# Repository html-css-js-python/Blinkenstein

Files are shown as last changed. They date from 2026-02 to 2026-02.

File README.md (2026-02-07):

# Blinkenstein

Blinkenstein is a simple KiCad PCB design intended as a functional test board.
It is designed to verify PCB manufacturing quality, assembly correctness, and basic
circuit functionality using classic CMOS logic.

## 1. Overview

Blinkenstein is an LED sequencing circuit built primarily from through-hole components,
with one SMD component included to verify mixed-technology assembly.
The design emphasizes simplicity, low power consumption, and ease of visual inspection.

## 2. Functional Description

The circuit sequentially activates LED pairs in the following order:

`RED → GREEN → BLUE → YELLOW`

Although eight LEDs are present on the PCB, only two LEDs are active at any given time.
The circuit serves as a functional indicator rather than a lighting device.

The core of the design is a CD4017 decade counter.
Clock pulses are generated by a discrete oscillator based on the tunneling effect.
These pulses are inverted and conditioned by a NOT gate with a Schmitt trigger input,
providing a clean and stable clock signal for the counter.

## 3. Schematic Diagram

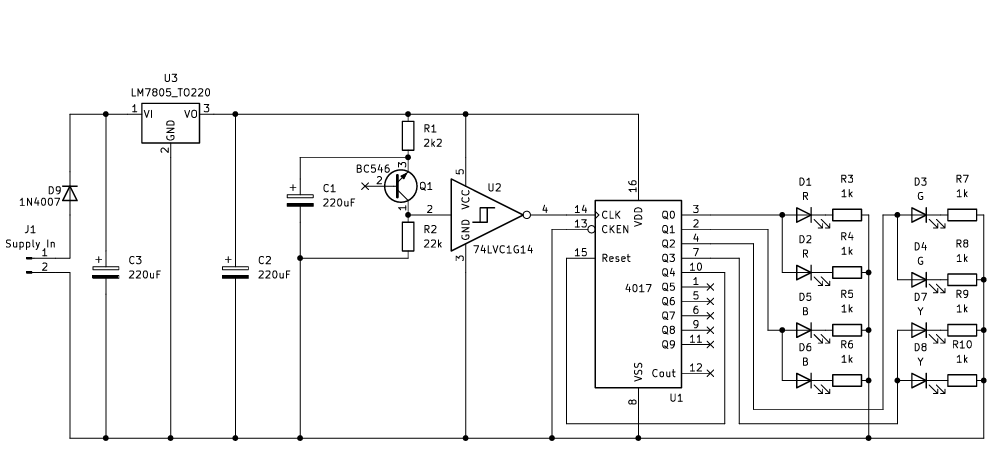
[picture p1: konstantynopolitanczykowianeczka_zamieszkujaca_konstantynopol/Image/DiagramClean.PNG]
Circuit Diagram

Figure 1. Blinkenstein schematic diagram

## 4. Electrical Characteristics

### 4.1 Recommended Operating Conditions

| Parameter | Symbol | Min | Typ | Max | Unit |
|---|---|-----|-----|-----|---|
| Supply Voltage | VCC | 7 | 9 | 12  | V |
| Supply Current | ICC | - | 100 | TBD | mA |
| Ambient Temperature  | TA | -20 | 25  | 60  | °C |

### 4.2 Power Consumption

| Operating Mode | Supply Voltage | Current | Notes |
|---|---|---|---|
| Normal operation | 9 V | ~100 mA | Two LEDs active  |

## 5. Power Supply Requirements

- DC input voltage range: 7–12 V
- Recommended supply voltage: 9 V
- Typical current consumption: ~100 mA
- External regulation not required

## 6. PCB and Assembly Notes

- Majority of components: through-hole
- One component: SMD (for mixed-technology assembly testing)
- Suitable for hand soldering and reflow (SMD component)

## 7. Intended Applications

- PCB manufacturing test board
- Assembly verification (THT + SMD)
- Educational demonstrations (CMOS counters and oscillators)
- Visual functional indicator

## 8. Project Files

All project files (schematic, PCB layout, Gerber)
are located in the following directory:

**[Project Files](/konstantynopolitanczykowianeczka_zamieszkujaca_konstantynopol)**

## 9. Notes

This project is not intended for high-power or precision timing applications.
Component values may be adjusted without affecting core functionality.
Original project name (may appear on schematics and PCB): `Migacz`

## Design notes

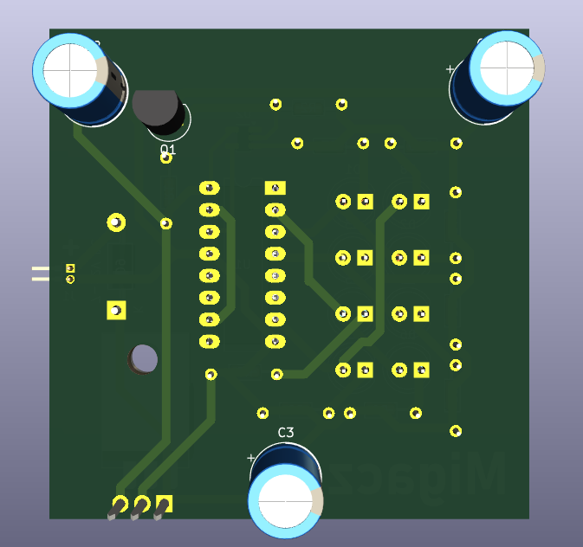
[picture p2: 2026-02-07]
konstantynopolitanczykowianeczka_zamieszkujaca_konstantynopol/Image/Model/BottomM.PNG

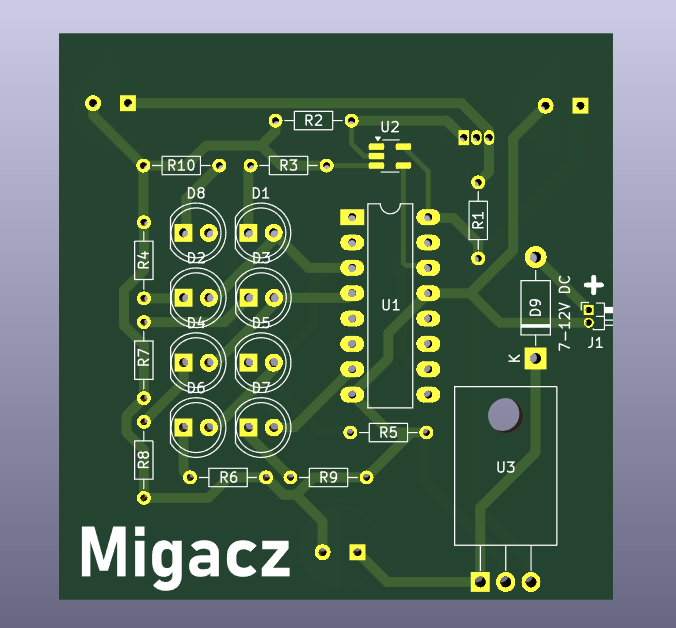
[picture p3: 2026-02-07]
konstantynopolitanczykowianeczka_zamieszkujaca_konstantynopol/Image/PCB/PCBTop.PNG

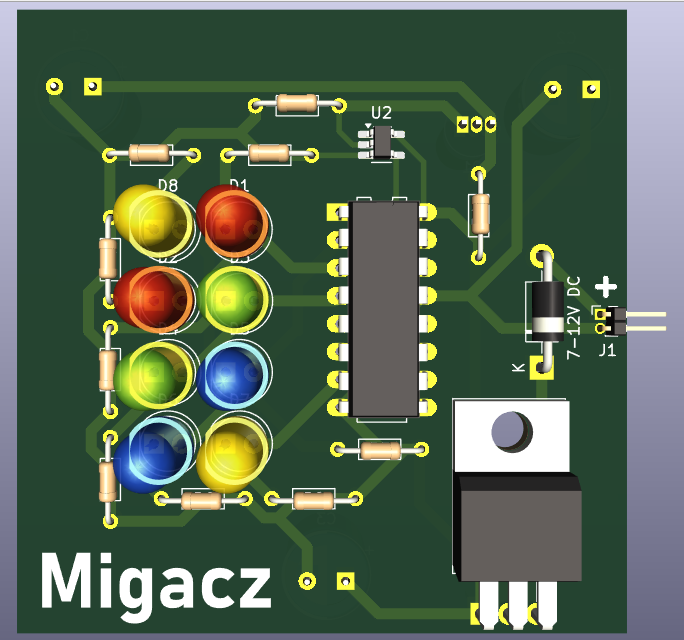
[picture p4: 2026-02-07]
konstantynopolitanczykowianeczka_zamieszkujaca_konstantynopol/Image/Model/TopM.PNG

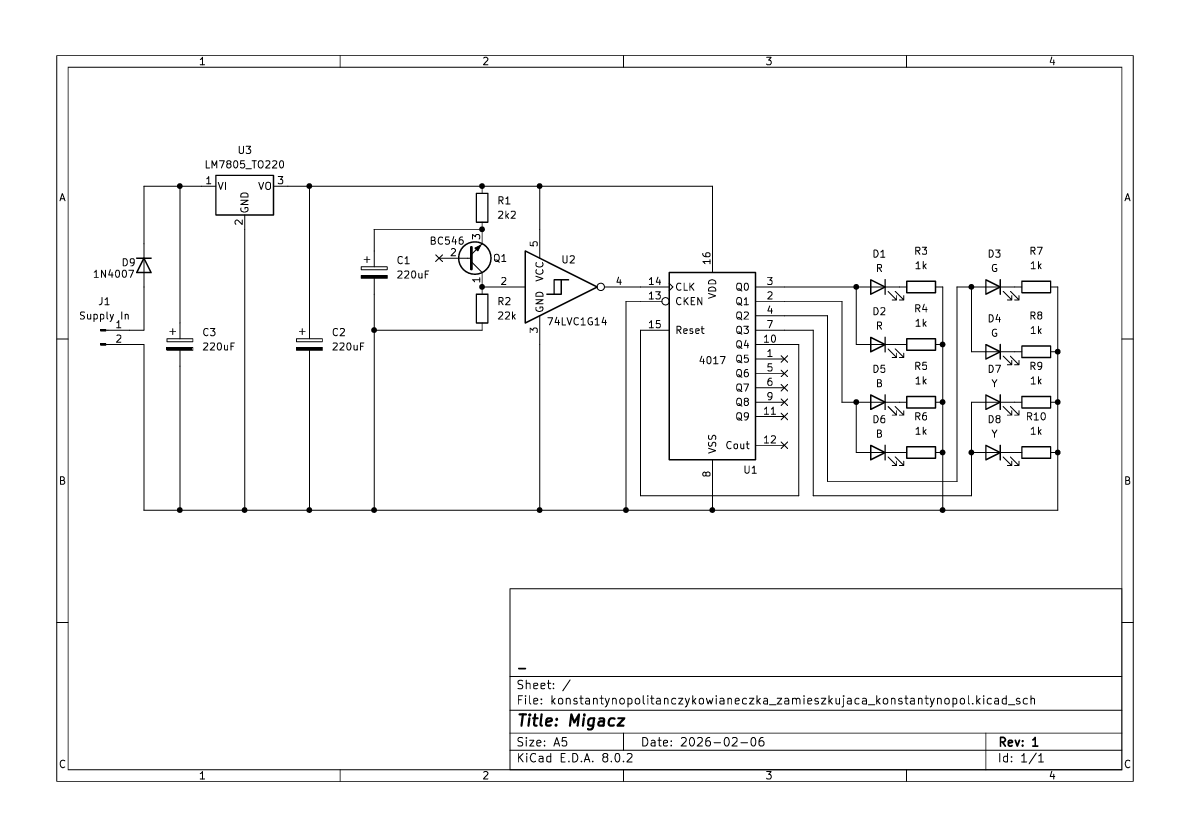
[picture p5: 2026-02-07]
konstantynopolitanczykowianeczka_zamieszkujaca_konstantynopol/Image/Diagram.PNG

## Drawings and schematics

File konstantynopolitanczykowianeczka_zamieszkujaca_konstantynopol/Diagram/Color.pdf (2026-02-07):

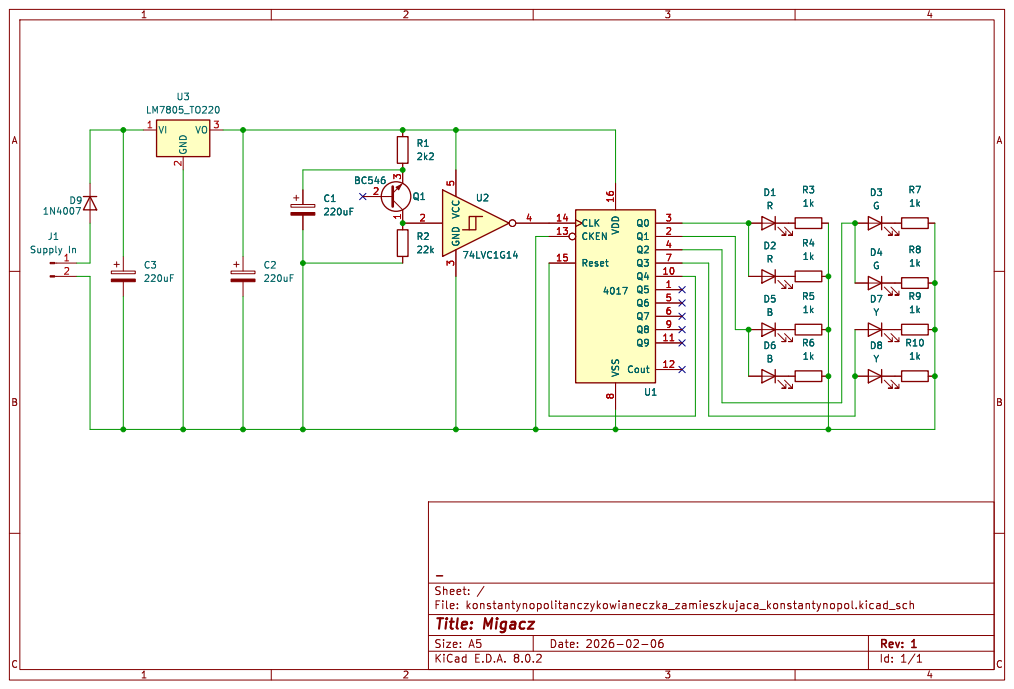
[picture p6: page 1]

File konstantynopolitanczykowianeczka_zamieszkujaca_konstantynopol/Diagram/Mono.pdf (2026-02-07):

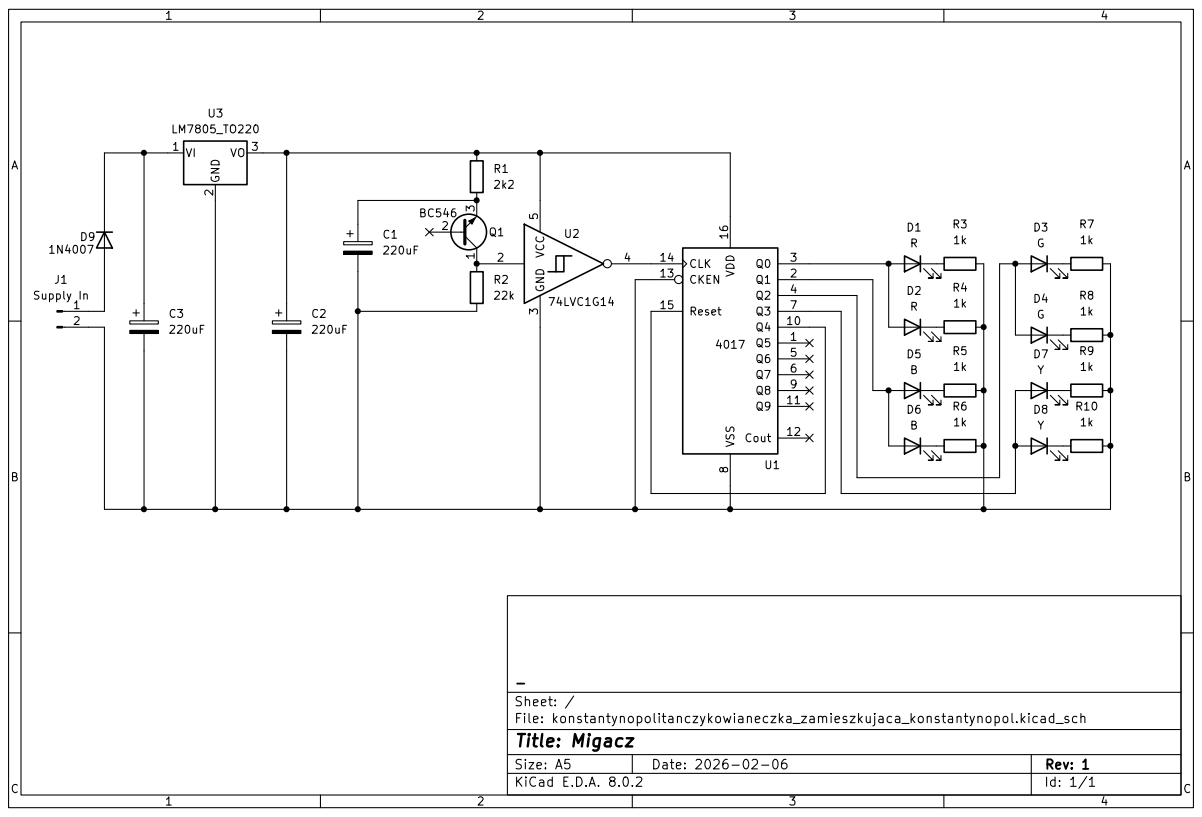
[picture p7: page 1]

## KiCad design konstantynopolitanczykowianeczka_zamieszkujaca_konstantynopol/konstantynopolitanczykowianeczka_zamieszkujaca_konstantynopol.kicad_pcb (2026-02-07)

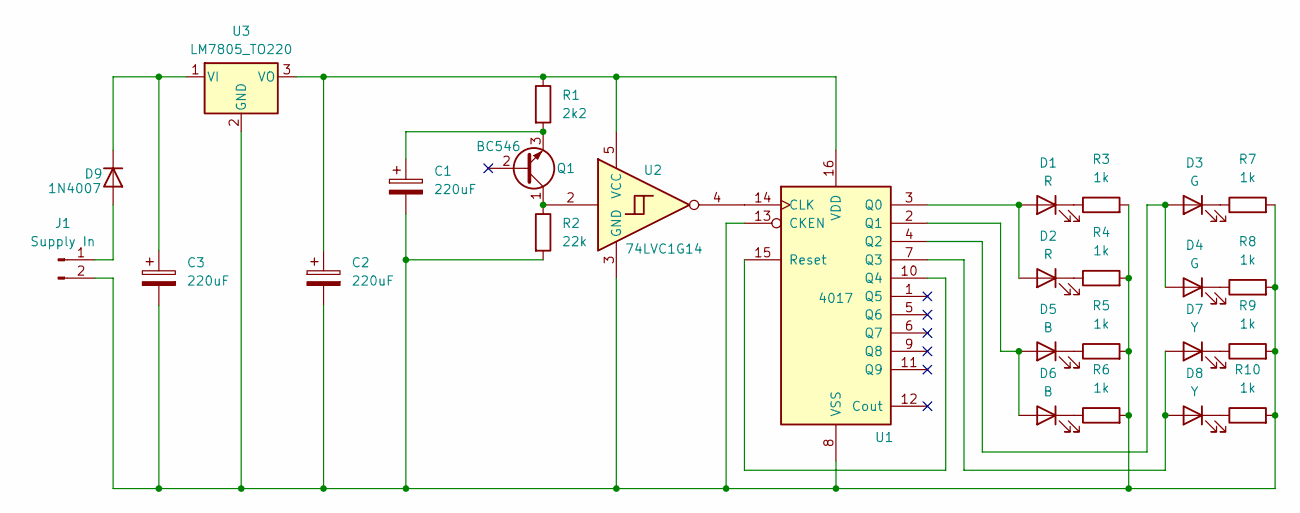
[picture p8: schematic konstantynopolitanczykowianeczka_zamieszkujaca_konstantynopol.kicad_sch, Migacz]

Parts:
C1, C2, C3: 220uF; CP_Radial_D8.0mm_P3.50mm
D1, D2: R; LED_D5.0mm
D3, D4: G; LED_D5.0mm
D5, D6: B; LED_D5.0mm
D7, D8: Y; LED_D5.0mm
D9: 1N4007; D_DO-41_SOD81_P10.16mm_Horizontal
J1: Supply In; PinHeader_1x02_P1.27mm_Horizontal
Q1: BC546; TO-92L_Inline
R1: 2k2; R_Axial_DIN0204_L3.6mm_D1.6mm_P7.62mm_Horizontal
R2: 22k; R_Axial_DIN0204_L3.6mm_D1.6mm_P7.62mm_Horizontal
R3, R4, R5, R6, R7, R8, R9, R10: 1k; R_Axial_DIN0204_L3.6mm_D1.6mm_P7.62mm_Horizontal
U1: 4017; DIP-16_W7.62mm_LongPads
U2: 74LVC1G14; SOT-23-5_HandSoldering
U3: LM7805_TO220; TO-220-3_Horizontal_TabDown

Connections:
unnamed: D1.2 (A), D2.2 (A), U1.3 (Q0)
unnamed: D1.1 (K), R3.1
unnamed: D2.1 (K), R4.1
unnamed: D3.2 (A), D4.2 (A), U1.4 (Q2)
unnamed: D3.1 (K), R7.1
unnamed: D4.1 (K), R8.1
unnamed: D5.2 (A), D6.2 (A), U1.2 (Q1)
unnamed: D5.1 (K), R5.1
unnamed: D6.1 (K), R6.1
unnamed: D7.2 (A), D8.2 (A), U1.7 (Q3)
unnamed: D7.1 (K), R9.1
unnamed: D8.1 (K), R10.1
unnamed: D9.2 (A), J1.1
unnamed: C3.1, D9.1 (K), U3.1 (VI)
unnamed: C1.2, C2.2, C3.2, J1.2, R2.2, R3.2, R4.2, R5.2, R6.2, R7.2, R8.2, R9.2, R10.2, U1.8 (VSS), U1.13 (CKEN), U2.3 (GND), U3.2 (GND)
unnamed: Q1.1 (C), R2.1, U2.2
unnamed: C1.1, Q1.3 (E), R1.2
unnamed: U1.14 (CLK), U2.4
unnamed: U1.10 (Q4), U1.15 (Reset)
unnamed: C2.1, R1.1, U1.16 (VDD), U2.5 (VCC), U3.3 (VO)

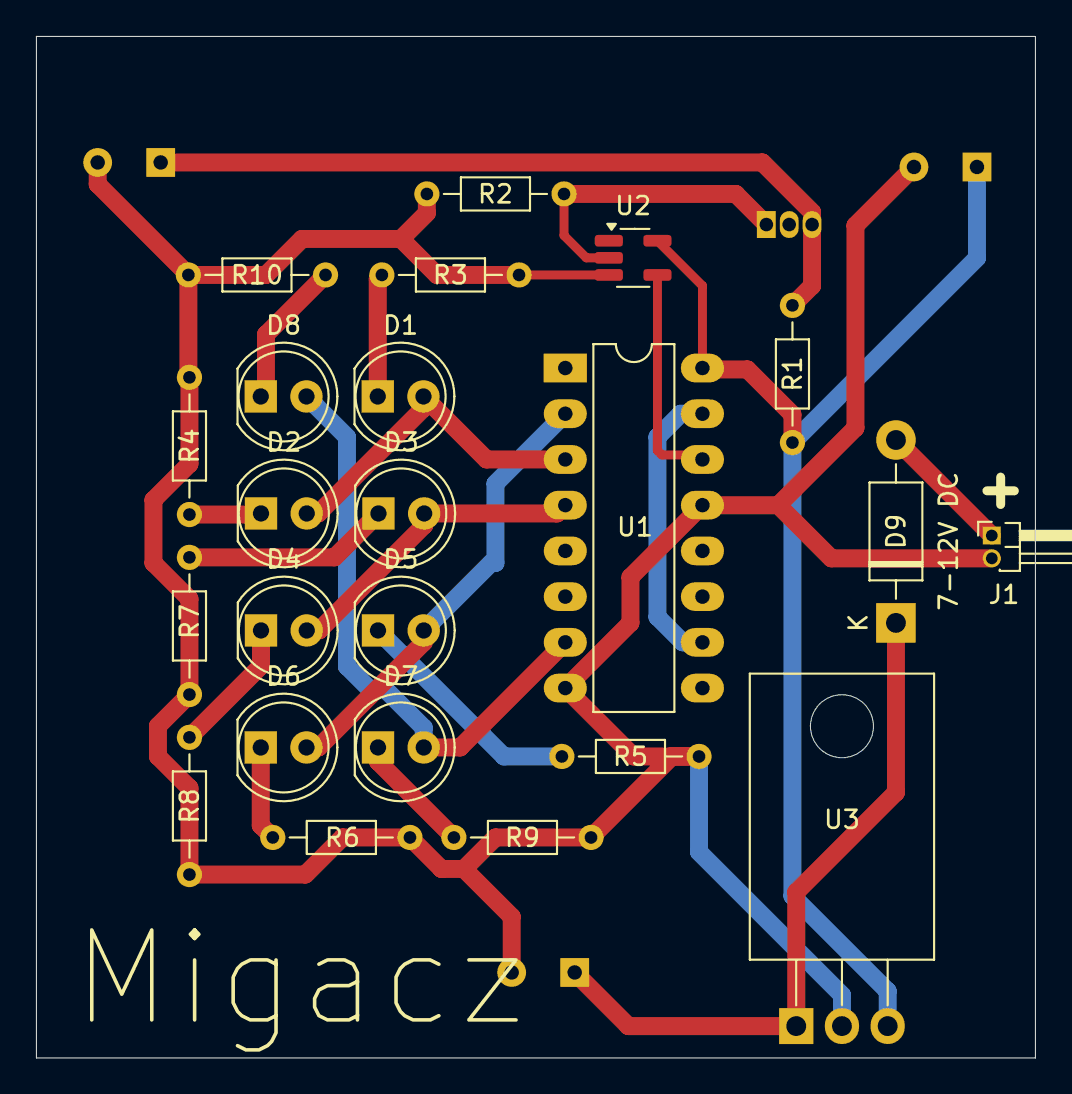
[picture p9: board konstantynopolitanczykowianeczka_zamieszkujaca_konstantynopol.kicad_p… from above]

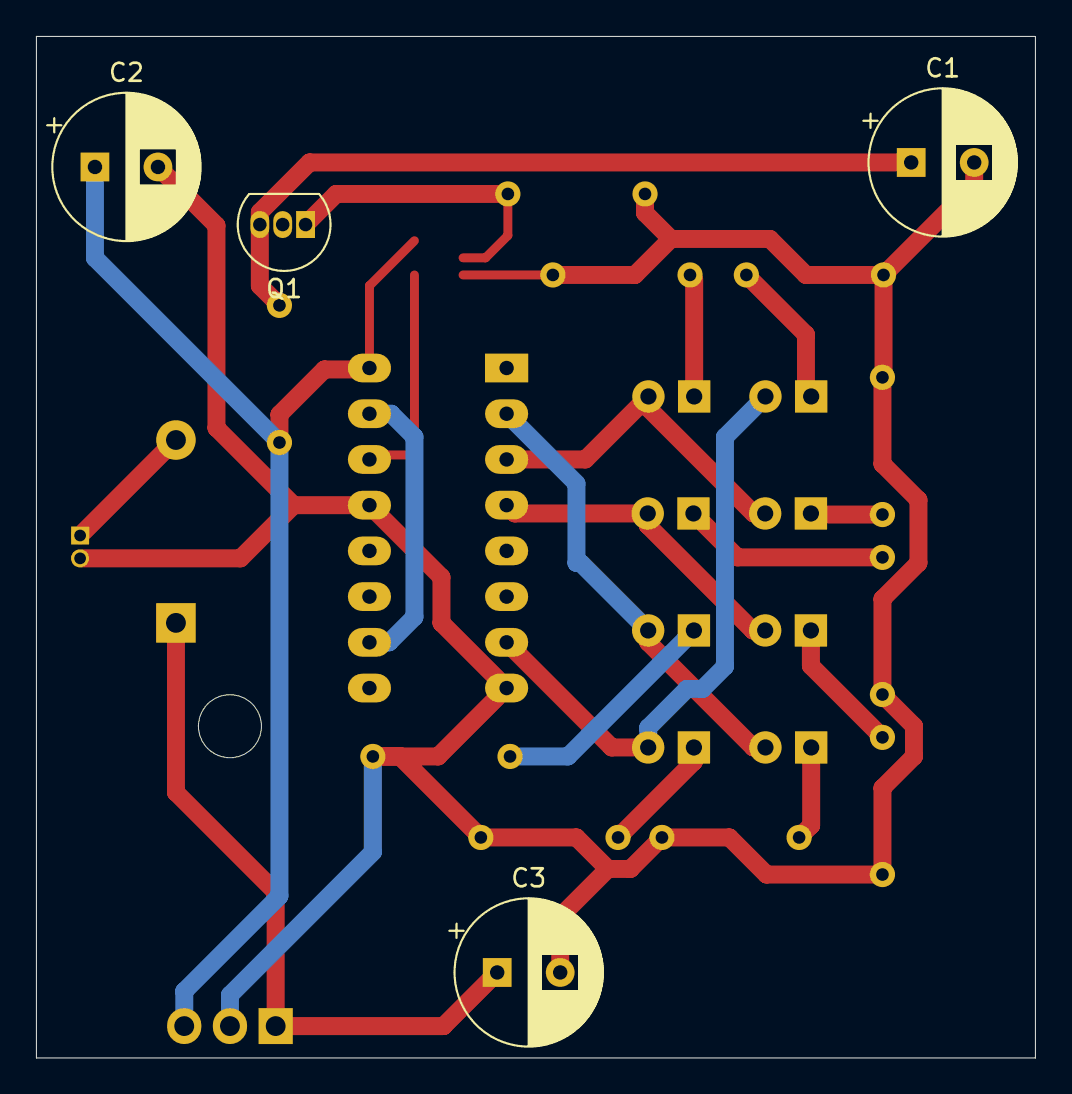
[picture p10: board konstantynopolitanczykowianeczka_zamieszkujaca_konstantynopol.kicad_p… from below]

Board: 2 copper layers, 55.5 x 56.8 mm, 27 parts (4 on the bottom side), 20 nets.
